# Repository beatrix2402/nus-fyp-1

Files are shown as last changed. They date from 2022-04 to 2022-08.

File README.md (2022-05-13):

# A low-cost device to detect angle closure glaucoma
This repository was created as part of my final year project at the National University of Singapore under the Department of Biomedical Engineering.

In this project, the development of a device using low-cost materials was explored to facilitate the [Standard Flashlight Test (SFT)](https://www.ncbi.nlm.nih.gov/pmc/articles/PMC5130941/), a simple test done that checks for primary angle closure glaucoma (PACG) in patients. This device was created with the intention of independent use by users regardless of technological skills as majority of the target audience are elderly.

## About the Project
A lightweight 3D-printed device (`CAD_files`) was built to solve the problem of infrequent testing for angle closure, which often lead to the unsuspected development of the disease and irreversible blindness. The device runs a Python code on a Raspberry Pi Zero (`startup_code_fyp.py`) to capture images of a patient’s eye with a camera and a light source. Thereafter, a deep learning algorithm built with PyTorch (`segmentation_code.ipynb`) segments the iris and determines the grading of primary angle closure suspect. The result is displayed to the patient through the device.

## About the Repository
In this repository, you will find the device code (`startup_code_fyp.py`), segmentation code (`segmentation_code`) and the CAD files used to print the device (`CAD_files`). Both are written in Python.

**The data for the segmentation code is not provided.** Please request it if necessary from marisa.lim@u.nus.edu.

## Segmentation Code
In the `segmentation_code` folder, you will find the models and Python notebook used. The `.html` and `.pdf` versions of the Python notebook are also included.

The necessary outputs are kept within for a better understanding of the notebook.

## Start-up Code
This Python code is run on a Raspberry Pi Zero in the device to automate the Standard Flashlight Test. The Raspberry Pi GPIO library was used.

## CAD Files
There are three components to the 3D-printed device: box top, box bottom, and LED holder. These are found in the `CAD_files` folder, which contains both the `.stl` and original SolidWorks files. An assembly file is also included within to visualise the three components together, with an additional eye cup to simulate the silicon eye cup that is attached later on.

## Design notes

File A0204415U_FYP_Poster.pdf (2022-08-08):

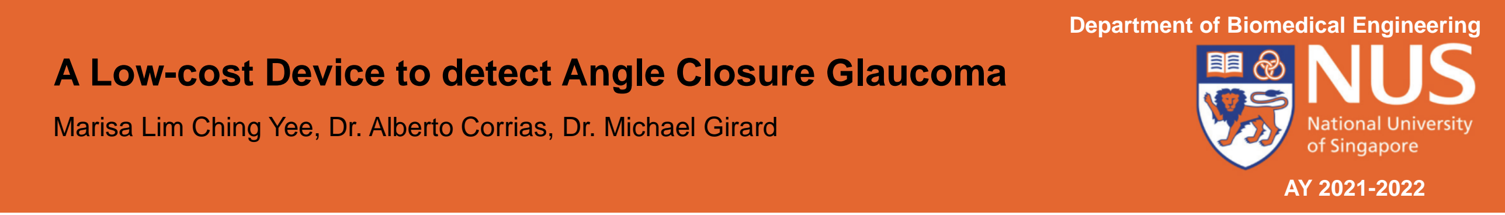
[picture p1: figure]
Department of Biomedical Engineering

## A Low-cost Device to detect Angle Closure Glaucoma

### Marisa Lim Ching Yee, Dr. Alberto Corrias, Dr. Michael Girard

- A device using low-cost materials was developed to automate the Standard Flashlight Test (SFT).
- PACG is a potentially preventable type of glaucoma if detected early enough with frequent screening. However, current screening techniques require professional supervision under a clinical setting [1].
- The SFT provides a cheap and convenient solution to accurately to identify risks of PACG in patients [3].
- By simply analysing the shadow cast over the iris by a beam of parallel light, the depth of the anterior chamber can be inferred, indicating if there is risk of PACG [Fig. 1, 4].

### Introduction

### Hardware Methodology

To automate the SFT process, these key items were used:
- A lightweight Raspberry Pi Zero microprocessor.
- Monocular-design casing 3D-printed with polylactic acid (PLA). Users simply rotate device to test each eye [Fig. 2].
- Tactile and audio prompts are given to the user during the SFT process when their vision is restricted.
- A silicon eyecup for users to position the tested eye.

Fig 2.
Components in
3D-printed PLA
casing.

### Software Methodology

Fig 3.
Categorisation
of grades of
PACG risk.

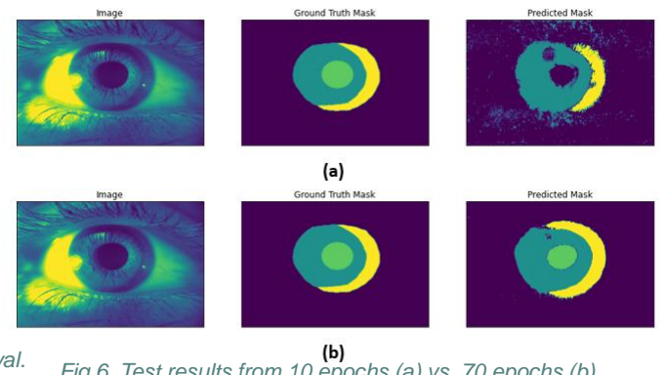
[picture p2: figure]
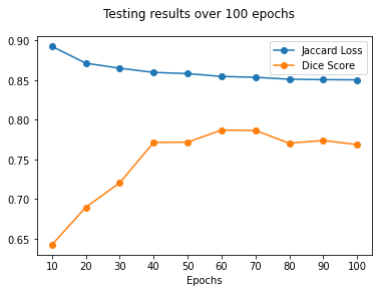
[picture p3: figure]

- While the segmentation of out-of-sample Grade 3 images was not as clean as those for Grade 1, the segments were still accurately identified [Fig. 7].
- A shadow-to-iris ratio was calculated by taking the area of the shadow (yellow) against that of the whole iris (teal, green and yellow). The larger the shadow area, the higher the ratio, thus indicating a higher risk of PACG (i.e., Grade 1).
Average ratio for Grade 1 = 0.2 Average ratio for Grade 3 = 0.199
- The minute difference can be attributed to the much smaller dataset for Grade 1, making the ratio unrepresentative of all Grade 1 eyes.
- Device was operated by the user with the help of an assistant of any skill level to guide their eyes [Fig. 4].
- Resulting images were of sufficient clarity, even capturing crypts with high definition, and the shadow cast on the iris by the light source can be clearly seen.

### Results and Discussion

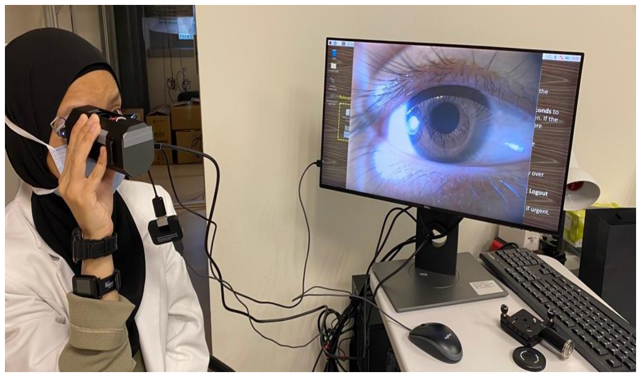
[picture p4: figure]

Fig 4. Example of resulting image (left) from the SFT process (right).

Fig 5. Testing results at each 10-epoch interval. Fig 6. Test results from 10 epochs (a) vs. 70 epochs (b).

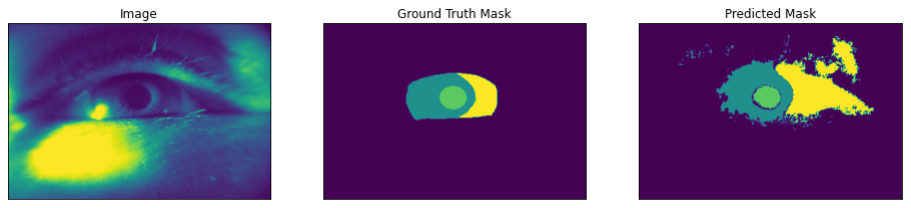
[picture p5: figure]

Fig 7. Test results on out-of-sample data from 70 training epochs.

[1] Sharma et al., 2008 – Diagnostic tools for glaucoma detection and management
[2] Shikino et. al, 2016 – Oblique flashlight test: Lighting up acute angle-closure Glaucoma
[3] Nongpiur et al., 2010 – Novel association of smaller anterior chamber width with angle closure in Singaporeans
[4] Sidhartha et al., 2014 – Relationship between iris surface features and angle width in Asian eyes

### References

- The device was successfully used without professional supervision to capture high quality images of the iris for Grade 1 and 3 users.
- The segmentation model was successfully trained to perform segmentation and obtain a ratio for multiclass classification into respective risk grades.
- Further training with other grades will allow development of a robust classification algorithm. Other factors indicating PACG risk such as crypt presence and eye colour can also be considered [4].
- Integration of the model onto the Raspberry Pi Zero via ONNX is recommended.

### Conclusion

A PyTorch deep learning algorithm was developed to identify 3 grades of PACG risk (Grades 1, 2, 3) [Fig. 3]. This stage focused on iris segmentation.

- 58 Grade 3 and 4 Grade 1 eyes.
- Segments: iris, shadow, pupil, others.
- All images were captured on device.
Building the Dataset | Model Training and Testing
| Training ▪ 100 epochs in total; data pulled, and best model saved every 10 epochs. Testing ▪ Each model was tested on Grade 3 testing set and out-of-sample Grade 1

testing set 4 (out-of-sample test)

41 (train) | 17 (test)

Fig. 1. Schematic of SFT.

- Optimal number of training epochs: 70 epochs [Fig. 5, 6].

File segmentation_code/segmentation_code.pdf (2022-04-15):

# Data Folder

The dataset is made up of images from three grades of PACS, in decreasing order of risk of PACG:

Grade 1 (G1) - high risk
Grade 2 (G2)
Grade 3 (G3) - low risk

Dataset is organised as such:

FOLDER NAME: "Data"

G3
images_original
images
labels
G2
(same as G1)
G1
(same as G1)

images_original contains the original RGB images obtained from the Raspberry Pi. images contains the pre-processed images into grayscale which will be used for the training and testing of the model. labels contains the segmentation PNG files from AVIZO.

# Data pre-processing

All images must first be converted from RGB to grayscale. These images will be stored in the "images" folder in each grade folder.

(1944, 2592, 3)
<matplotlib.image.AxesImage at 0x20dc1121940>

(1944, 2592, 3)
<matplotlib.image.AxesImage at 0x20dc1189430>

# Load data

Allocate pre-processed images from "images" and target from "labels" into train and test set.

In this code, the model is only trained on G3 images. G1 images are used as out-of-sample test data.

Number of Grade 3 images: 58 Total number of images: 58

Number of Training images: 41 Number of Testing images: 17

## Visualize function

Takes in images as arrays and prints them using Matplotlib.

## Dataloader

Writing helper class for data extraction, tranformation and preprocessing https://pytorch.org/docs/stable/data

Done!

## Augmentations

Data augmentation is a powerful technique to increase the amount of your data and prevent model overfitting. If you not familiar with such trick read some of these articles:

The Effectiveness of Data Augmentation in Image Classification using Deep Learning (http://cs231n.stanford.edu/reports/2017/pdfs/300.pdf)
Data Augmentation | How to use Deep Learning when you have Limited Data (https://medium.com/nanonets/how-to-use-deep-learning-when-you-have-limited-data-part-2-data-augmentation-c26971dc8ced)
Data Augmentation Experimentation (https://towardsdatascience.com/data-augmentation-experimentation-3e274504f04b)

Since our dataset is very small we will apply a large number of different augmentations:

horizontal flip
affine transforms
perspective transforms
brightness/contrast/colors manipulations image bluring and sharpening gaussian noise
random crops

All this transforms can be easily applied with Albumentations (https://github.com/albu/albumentations/) - fast augmentation library. For detailed explanation of image transformations you can look at kaggle salt segmentation exmaple (https://github.com/albu/albumentations/blob/master/notebooks/example_kaggle_salt.ipynb) provided by Albumentations (https://github.com/albu/albumentations/) authors.

Size of augmented dataset: 41

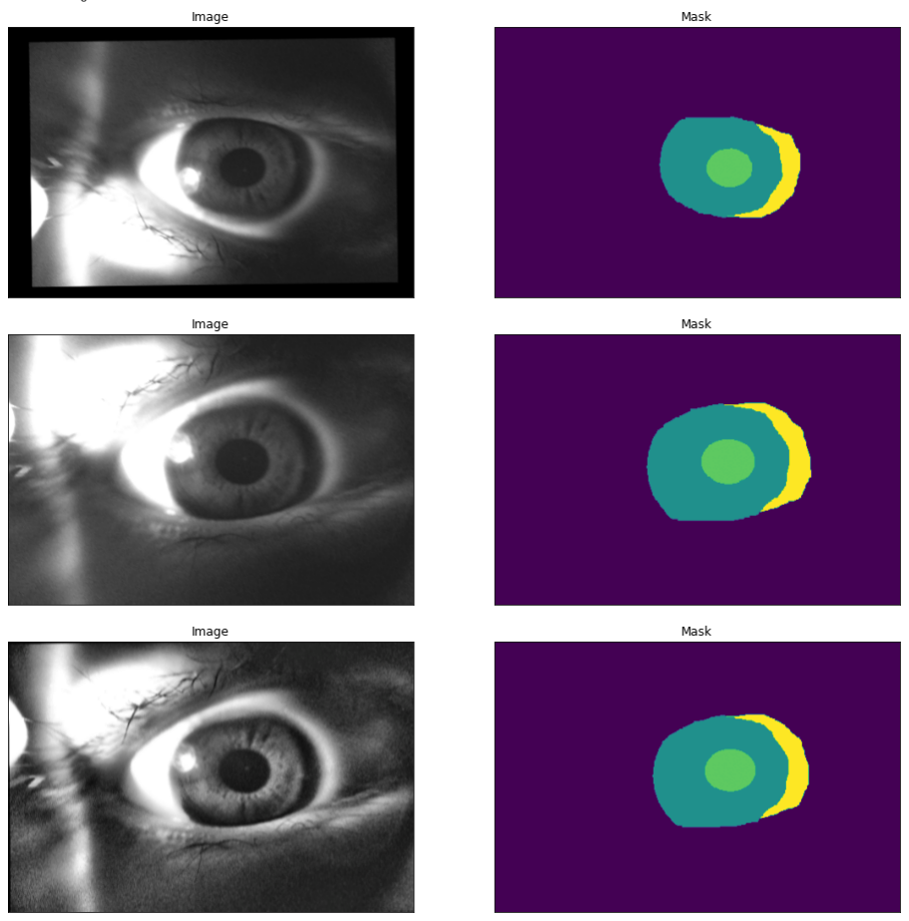
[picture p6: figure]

# Create model and train

Epoch: 0
train: 100%|█████████████████████████████████████| 6/6 [01:08<00:00, 11.44s/it, jaccard_loss - 0.8559, fscore - 0.7569] Model saved!

Epoch: 1
train: 100%|█████████████████████████████████████| 6/6 [01:00<00:00, 10.07s/it, jaccard_loss - 0.8608, fscore - 0.7371] Decrease decoder learning rate to 1e-5!

Epoch: 2
train: 100%|█████████████████████████████████████| 6/6 [00:57<00:00, 9.59s/it, jaccard_loss - 0.8667, fscore - 0.7235]

Epoch: 3
train: 100%|█████████████████████████████████████| 6/6 [00:57<00:00, 9.51s/it, jaccard_loss - 0.8582, fscore - 0.7497]

Epoch: 4
train: 100%|███████████████████████████████████████| 6/6 [00:57<00:00, 9.54s/it, jaccard_loss - 0.8567, fscore - 0.75]

Epoch: 5
train: 100%|█████████████████████████████████████| 6/6 [00:57<00:00, 9.61s/it, jaccard_loss - 0.8566, fscore - 0.7576] Model saved!

Epoch: 6
train: 100%|█████████████████████████████████████| 6/6 [00:59<00:00, 9.87s/it, jaccard_loss - 0.8617, fscore - 0.7335]

Epoch: 7
train: 100%|███████████████████████████████████████| 6/6 [00:57<00:00, 9.59s/it, jaccard_loss - 0.85, fscore - 0.7545]

Epoch: 8
train: 100%|███████████████████████████████████████| 6/6 [00:56<00:00, 9.50s/it, jaccard_loss - 0.859, fscore - 0.743]

Epoch: 9
train: 100%|█████████████████████████████████████| 6/6 [00:57<00:00, 9.55s/it, jaccard_loss - 0.8602, fscore - 0.7318]

# Test best saved model on G3 test data

Model is tested on the pre-allocated test data (G3). The model used below is extracted after 70 training epochs, which is the optimal training duration (see last section: Results and Plotting).

valid: 100%|███████████████████████████████████| 17/17 [00:11<00:00, 1.47it/s, jaccard_loss - 0.8536, fscore - 0.7866]

# Visualize testing predictions

All testing predictions will be saved into a folder called "results".

# Finding colour ratio

This will give some insight into the ratio of the shadow to iris.

RGB values:

White: (255, 255, 255)
Dark purple (background colour): (68, 1, 84) Teal (iris): (32, 144, 140)
Yellow (shadow): (253, 231, 36)
Green (pupil): (94, 201, 97)
Black: (13, 0, 17)

*Numbers with very similar values can be counted towards the colour category

FOR IMAGE: ./Data/G3/results/TRAINING7_0.png | Ratio: 0.1478351319724353
FOR IMAGE: ./Data/G3/results/TRAINING7_1.png | Ratio: 0.1515783618411904
FOR IMAGE: ./Data/G3/results/TRAINING7_2.png | Ratio: 0.22361336076697458
FOR IMAGE: ./Data/G3/results/TRAINING7_3.png | Ratio: 0.22768361581920904
FOR IMAGE: ./Data/G3/results/TRAINING7_4.png | Ratio: 0.1980398100434475
FOR IMAGE: ./Data/G3/results/TRAINING7_5.png | Ratio: 0.1462166364343094
FOR IMAGE: ./Data/G3/results/TRAINING7_6.png | Ratio: 0.24132389349780653
FOR IMAGE: ./Data/G3/results/TRAINING7_7.png | Ratio: 0.18103517026876145
FOR IMAGE: ./Data/G3/results/TRAINING7_8.png | Ratio: 0.239057524941626
FOR IMAGE: ./Data/G3/results/TRAINING7_9.png | Ratio: 0.21289220107276782
FOR IMAGE: ./Data/G3/results/TRAINING7_10.png | Ratio: 0.24365106479899784
FOR IMAGE: ./Data/G3/results/TRAINING7_11.png | Ratio: 0.1893248879962923
FOR IMAGE: ./Data/G3/results/TRAINING7_12.png | Ratio: 0.18408450073848634
FOR IMAGE: ./Data/G3/results/TRAINING7_13.png | Ratio: 0.15226569096538137
FOR IMAGE: ./Data/G3/results/TRAINING7_14.png | Ratio: 0.17349596319124924
FOR IMAGE: ./Data/G3/results/TRAINING7_15.png | Ratio: 0.24597881522165554
FOR IMAGE: ./Data/G3/results/TRAINING7_16.png | Ratio: 0.21564569536423842

# Out-of-sample G1 test data

There are currently 4 G1 images, which will be used as out-of-sample test data to evaluate the ability of the model to run on different grades.

valid: 100%|█████████████████████████████████████| 4/4 [00:02<00:00, 1.63it/s, jaccard_loss - 0.9448, fscore - 0.5109]

FOR IMAGE: ./Data/G3/results/OOS_TRAINING7_0.png | Ratio: 0.15514764565043895
FOR IMAGE: ./Data/G3/results/OOS_TRAINING7_1.png | Ratio: 0.18888546798029557
FOR IMAGE: ./Data/G3/results/OOS_TRAINING7_2.png | Ratio: 0.16101873289833718
FOR IMAGE: ./Data/G3/results/OOS_TRAINING7_3.png | Ratio: 0.2977827673309009

# Results and Plotting

The following results were collected after training and testing of the model over 100 epochs, and data was collected every 10 epochs to find the optimal training epoch number.

In [ ]:
import os, glob, shutil
os.environ['CUDA_VISIBLE_DEVICES'] = ''

import numpy as np
import cv2
import matplotlib
import matplotlib.pyplot as plt import matplotlib._png as png import torch
from PIL import Image
#from time import process_time

#torch.cuda.empty_cache()

print("Import done")

In [22]:
DATA_DIR = './Data/' # change as per the name of the data folder

In [23]:
# CONVERT IMAGES TO GRAYSCALE

def processSkinImage(filePath):
# step 1

# read the image

original = cv2.imread(filename=filePath)

# step 2

# convert the image from rgb to grayscale

image_gray = cv2.cvtColor(original, cv2.COLOR_BGR2GRAY)

return image_gray

In [ ]:
# Process G3 images

path = './Data/G3/images_original' path_processed = './Data/G3/images'
for mainDir, subDir, fileList in os.walk(path): for file in fileList:
currentPath = os.path.join(mainDir, file) processedImage = processSkinImage(currentPath)

new_mainDir = path_processed + mainDir.split(path)[-1]
if not os.path.exists(new_mainDir): os.makedirs(new_mainDir)
cv2.imwrite(os.path.join(new_mainDir, file), processedImage)

print("G3 images processed")

# Process G1 images

path = './Data/G1/images_original' path_processed = './Data/G1/images'
for mainDir, subDir, fileList in os.walk(path): for file in fileList:
currentPath = os.path.join(mainDir, file) processedImage = processSkinImage(currentPath)

new_mainDir = path_processed + mainDir.split(path)[-1]
if not os.path.exists(new_mainDir): os.makedirs(new_mainDir)
cv2.imwrite(os.path.join(new_mainDir, file), processedImage)

print("G1 images processed")

In [25]:
# SHOW SAMPLE OF ORIGINAL IMAGE

filePath = "./Data/G3/images_original/G3_L1.png" original = cv2.imread(filename=filePath)
original = cv2.cvtColor(original, cv2.COLOR_BGR2RGB) print(original.shape)
plt.imshow(original)

# Out[25]: In [26]:

# SHOW SAMPLE OF GRAYSCALED IMAGE

filePath = "./Data/G3/images/G3_L1.png" gray = cv2.imread(filename=filePath) print(gray.shape)
plt.imshow(gray, cmap='gray')

# Out[26]: In [27]:

import fnmatch

num_G3_total = len(fnmatch.filter(os.listdir('./Data/G3/images/'),'*.png')) # Grade 3 - Healthy eyes #num_G2_total = len(fnmatch.filter(os.listdir('./Data/G2/images/'),'*.png')) # Grade 2 num_G1_total = len(fnmatch.filter(os.listdir('./Data/G1/images/'),'*.png')) # Grade 1
print( 'Number of Grade 3 images:', num_G3_total) #58

print( 'Total number of images:', num_G3_total) # + num_G2_total+ num_G1_total

In [28]:
# ALLOCATE TRAIN AND TEST

# percentage used for testing - can be changed percentage_testing = 0.3

num_G3_testing = int(num_G3_total * percentage_testing) num_G3_training = num_G3_total - num_G3_testing

num_training = num_G3_training #+ num_G2_training + num_G1_training num_testing = num_G3_testing #+ num_G2_testing + num_G1_testing print( 'Number of Training images:', num_training)
print( 'Number of Testing images:', num_testing)

files_G3_images = sorted(os.listdir(os.path.join('./Data/G3/images/'))) files_G3_labels = sorted(os.listdir(os.path.join('./Data/G3/labels/')))

In [29]:
k = 0
row = 256
col = 256
num_classes = 5 # CHANGE ACCORDING TO HOW MANY MATERIALS used in segmentation

# Define some arrays --- This is for Keras

X_train | = np.ndarray(shape=(num_training, row, col, | 1), dtype='d')
Y_train | = np.ndarray(shape=(num_training, row, col, num_classes), dtype='d')
X_test | = np.ndarray(shape=(num_testing , row, col, | 1), dtype='d')
Y_test | = np.ndarray(shape=(num_testing , row, col, num_classes), dtype='d')

In [ ]:
# Training Set--------------------------------------------------------------------------------print("TRAINING SET:")

for i in range(num_G3_training):

# add image

im = plt.imread(os.path.join('./Data/G3/images/',files_G3_images[i+1])) X_train[k,:,:,0] = cv2.resize(im, dsize=(col, row), interpolation=cv2.INTER_LINEAR)

la = plt.imread(os.path.join('./Data/G3/labels/',files_G3_labels[i+1]))

# add label

rla = cv2.resize(la[:,:], dsize=(col, row), interpolation=cv2.INTER_NEAREST) for j in range(num_classes):
| temp = np.copy(rla)+1 temp[temp!=j+1] = 0 Y_train[k,:,:,j] = temp/(j+1)

k = k+1
print(files_G3_images[i+1]+', '+files_G3_labels[i+1]+' added')

print("Done!")

In [ ]:
# Testing Set--------------------------------------------------------------------------------print("TESTING SET:")

k=0
for i in range(num_G3_testing):

# add image

im = plt.imread(os.path.join('./Data/G3/images/',files_G3_images[num_G3_training+1+i])) X_test[k,:,:,0] = cv2.resize(im, dsize=(col, row), interpolation=cv2.INTER_LINEAR)

# add label

la = plt.imread(os.path.join('./Data/G3/labels/',files_G3_labels[num_G3_training+i])) rla = cv2.resize(la[:,:], dsize=(col, row), interpolation=cv2.INTER_NEAREST)

for j in range(num_classes):
| temp = np.copy(rla)+1 temp[temp!=j+1] = 0 Y_test[k,:,:,j] = temp/(j+1)

k = k+1

print(files_G3_images[num_G3_training+1+i]+', '+files_G3_labels[num_G3_training+i]+' added')
#if "list index out of range" just add +1 or remove +1. This is due to the .ipynb_checkpoints folder

print("Done!")

In [ ]:
# Direct into Train, Validation, and Test Folders x_train_dir = os.path.join(DATA_DIR, 'train') y_train_dir = os.path.join(DATA_DIR, 'trainannot') #x_valid_dir = os.path.join(DATA_DIR, 'val') #y_valid_dir = os.path.join(DATA_DIR, 'valannot')

x_test_dir = os.path.join(DATA_DIR, 'test')
y_test_dir = os.path.join(DATA_DIR, 'testannot')

# We delete all the files in them in case we want to change the proportions for f in glob.glob(os.path.join(x_train_dir,'*')): os.remove(f)

for f in glob.glob(os.path.join(y_train_dir,'*')): os.remove(f)
for f in glob.glob(os.path.join(x_test_dir,'*')): os.remove(f)
for f in glob.glob(os.path.join(y_test_dir,'*')): os.remove(f)

# Training Set--------------------------------------------------------------------------------print("TRAIN FOLDERS:")

for i in range(num_G3_training): shutil.copy(os.path.join('./Data/G3/images/',files_G3_images[i+1]), x_train_dir) shutil.copy(os.path.join('./Data/G3/labels/',files_G3_labels[i+1]), y_train_dir) print(files_G3_images[i+1]+', '+files_G3_labels[i+1]+' copied!')

# Testing Set--------------------------------------------------------------------------------print("TEST FOLDERS:")

for i in range(num_G3_testing): shutil.copy(os.path.join('./Data/G3/images/',files_G3_images[num_G3_training+1+i]), x_test_dir) shutil.copy(os.path.join('./Data/G3/labels/',files_G3_labels[num_G3_training+i]), y_test_dir) print(files_G3_images[num_G3_training+1+i]+', '+files_G3_labels[num_G3_training+i]+' copied!')

In [33]:
# helper function for data visualization def visualize(**images):

"""Plot images in one row."""
n = len(images)
plt.figure(figsize=(16, 5))
for i, (name, image) in enumerate(images.items()): plt.subplot(1, n, i + 1)
plt.xticks([])
plt.yticks([])
plt.title(' '.join(name.split('_')).title()) plt.imshow(image)
plt.show()

In [34]:
from torch.utils.data import DataLoader
from torch.utils.data import Dataset as BaseDataset

In [35]:
class Dataset(BaseDataset):
"""CamVid Dataset. Read images, apply augmentation and preprocessing transformations.

Args:
images_dir (str): path to images folder
masks_dir (str): path to segmentation masks folder
class_values (list): values of classes to extract from segmentation mask augmentation (albumentations.Compose): data transfromation pipeline (e.g. flip, scale, etc.)
preprocessing (albumentations.Compose): data preprocessing
(e.g. noralization, shape manipulation, etc.)

"""

CLASSES = ['0','1', '2', '3','4'] # 4 materials used in segmentation

def __init__(
self,
images_dir,
masks_dir,
classes=None,
augmentation=None,
preprocessing=None,
):
self.ids = sorted(os.listdir(images_dir))
self.images_fps = [os.path.join(images_dir, image_id) for image_id in self.ids]
#self.masks_fps = [os.path.join(masks_dir, image_id) for image_id in self.ids]

self.masks_fps = [os.path.join(masks_dir, image_id) for image_id in sorted(os.listdir(masks_dir))]

# convert str names to class values on masks

self.class_values = [self.CLASSES.index(cls.lower()) for cls in classes]

self.augmentation = augmentation
self.preprocessing = preprocessing

def __getitem__(self, i):

# read data

image = cv2.imread(self.images_fps[i])
image = cv2.resize(image, dsize=(480, 320), interpolation=cv2.INTER_NEAREST)

mask = cv2.imread(self.masks_fps[i], 0)
mask = cv2.resize(mask, dsize=(480, 320), interpolation=cv2.INTER_NEAREST)

# extract certain classes from mask (e.g. cars)

masks = [(mask == v) for v in self.class_values]
mask = np.stack(masks, axis=-1).astype('float')

# apply augmentations

if self.augmentation:
sample = self.augmentation(image=image, mask=mask) image, mask = sample['image'], sample['mask']

# apply preprocessing

if self.preprocessing:
sample = self.preprocessing(image=image, mask=mask) image, mask = sample['image'], sample['mask']

return image, mask

def __len__(self):
return len(self.ids)

In [36]:
# Lets look at data we have

dataset = Dataset(x_train_dir, y_train_dir, classes=['0','1','2','3','4']) # Somehow need one more class than required to work print("Done!")

In [37]:
# print sample 0

i = 0
image, mask = dataset[i] # get some sample

mask2 = np.zeros((mask.shape[0], mask.shape[1])) for i in range(num_classes):
mask2 += mask[:,:,i]*i

visualize(
image=image,
seg_mask=mask2.squeeze(),
)

In [ ]:
# print everything

for i in range(num_training):
image, mask = dataset[i] # get some sample

mask2 = np.zeros((mask.shape[0], mask.shape[1])) for i in range(num_classes):
mask2 += mask[:,:,i]*i

visualize(
image=image,
seg_mask=mask2.squeeze(),
)

In [38]:
import albumentations as albu

In [39]:
# ORIGINAL AUGMENTATIONS

def get_training_augmentation():

train_transform = [

albu.VerticalFlip(p=0.5), # Vertical flip to simulate difference between left and right eye.

albu.ShiftScaleRotate(scale_limit=0.1, rotate_limit=1, shift_limit=0.01, p=1, border_mode=0),

#albu.RandomBrightness(limit=0.1, p=0.8),

#albu.RandomContrast(limit=0.1, p=0.8),

#albu.Blur(blur_limit=3, p=0.8),

#albu.MotionBlur(blur_limit=3, p=0.8),

albu.OneOf(
[
albu.CLAHE(p=1),
albu.RandomBrightness(limit=0.1, p=1), albu.RandomGamma(p=1),
],
p=0.8,
),

albu.OneOf(
[
# | albu.IAASharpen(p=1),

| albu.Blur(blur_limit=3, p=1),
| albu.MotionBlur(blur_limit=3, p=1),
],
p=0.8,
),

albu.OneOf(
[
| albu.RandomContrast(p=1),
],
p=0.5,
),
]
return albu.Compose(train_transform)

def get_validation_augmentation():
"""Add paddings to make image shape divisible by 32""" test_transform = [
albu.PadIfNeeded(384, 480)
]
return albu.Compose(test_transform)

def to_tensor(x, **kwargs):
return x.transpose(2, 0, 1).astype('float32')

def get_preprocessing(preprocessing_fn): """Construct preprocessing transform

Args:
preprocessing_fn (callbale): data normalization function (can be specific for each pretrained neural network) Return:
transform: albumentations.Compose

"""

_transform = [
albu.Lambda(image=preprocessing_fn), albu.Lambda(image=to_tensor, mask=to_tensor), ]
return albu.Compose(_transform)

In [42]:
#### Visualize resulted augmented images and masks

augmented_dataset = Dataset(
x_train_dir,
y_train_dir,
augmentation=get_training_augmentation(), classes=['0','1','2','3','4'],
)

print("Size of augmented dataset: ", len(augmented_dataset))

# same image with different random transforms

for i in range(3):
image, mask = augmented_dataset[0]
mask2 = np.zeros((mask.shape[0], mask.shape[1])) for j in range(num_classes): mask2 += mask[:,:,j]*j visualize(image=image, mask=mask2.squeeze())

In [50]:
import torch
import numpy as np
import segmentation_models_pytorch as smp

In [ ]:
ENCODER = 'resnet34'
ENCODER_WEIGHTS = 'imagenet'
CLASSES = ['0','1','2','3','4']
ACTIVATION = 'softmax2d' # could be None for logits or 'softmax2d' for multicalss segmentation DEVICE = 'cpu' #cuda

# create segmentation model with pretrained encoder

model = smp.UnetPlusPlus(
encoder_name=ENCODER,
encoder_weights=ENCODER_WEIGHTS, #in_channels=1,
classes=len(CLASSES),
activation=ACTIVATION,
)

preprocessing_fn = smp.encoders.get_preprocessing_fn(ENCODER, ENCODER_WEIGHTS) print("Model created!")

In [ ]:
train_dataset = Dataset(
x_train_dir,
y_train_dir,
augmentation=get_training_augmentation(), preprocessing=get_preprocessing(preprocessing_fn), classes=CLASSES,
)

print("Data loaded!")

train_loader = DataLoader(train_dataset, batch_size=8, shuffle=True, num_workers=0)
# issue resolved (num_workers): https://github.com/pytorch/pytorch/issues/5301

In [53]:
# Dice/F1 score - https://en.wikipedia.org/wiki/S%C3%B8rensen%E2%80%93Dice_coefficient # IoU/Jaccard score - https://en.wikipedia.org/wiki/Jaccard_index

loss = smp.utils.losses.JaccardLoss()
metrics = [
#smp.utils.metrics.IoU(threshold=0.5), smp.utils.metrics.Fscore(threshold=0.5),

]

optimizer = torch.optim.Adam([ dict(params=model.parameters(), lr=0.0001), ])

In [ ]:
# create epoch runners

# it is a simple loop of iterating over dataloader`s samples train_epoch = smp.utils.train.TrainEpoch(

model,
loss=loss,
metrics=metrics,
optimizer=optimizer,
device=DEVICE,
verbose=True,
)

print("Done!")

In [324…
# train model for specific number of epochs

max_score = 0

for i in range(0, 10): # CHANGE THE NUMBER OF EPOCHS

print('\nEpoch: {}'.format(i))
train_logs = train_epoch.run(train_loader)

torch.save(model.state_dict(),'./essai.pth')

# do something (save model, change lr, etc.) if max_score < train_logs['fscore']:

max_score = train_logs['fscore']

# ALWAYS CHANGE THE NAME OF THE SAVED MODEL

torch.save(model, './Models/best_model_training_epoch_100.pth') print('Model saved!')

if i == 1:
optimizer.param_groups[0]['lr'] = 1e-5
print('Decrease decoder learning rate to 1e-5!')

In [55]:
# load best saved checkpoint

best_model = torch.load('./Models/best_model_training_epoch_70.pth') # MUST CHANGE THE NAME AS WELL

In [56]:
# create test dataset with G3 data

test_dataset = Dataset(
x_test_dir,
y_test_dir,
preprocessing=get_preprocessing(preprocessing_fn), classes=CLASSES,
)

test_dataloader = DataLoader(test_dataset)

In [57]:
# evaluate model on test set

test_epoch = smp.utils.train.ValidEpoch( model=best_model,
loss=loss,
metrics=metrics,
device=DEVICE,
)

logs = test_epoch.run(test_dataloader) # COPY THE LOGS AND STORE IT SOMEWHERE

In [59]:
# test dataset without transformations for image visualization test_dataset_vis = Dataset(

x_test_dir, y_test_dir,
classes=CLASSES,
)

In [61]:
# Show samples

for n in range(1):

image_vis = test_dataset_vis[n][0].astype('uint8') image, gt_mask = test_dataset[n]

gt_mask = gt_mask.squeeze()

x_tensor = torch.from_numpy(image).to(DEVICE).unsqueeze(0) pr_mask = best_model.predict(x_tensor)
pr_mask = (pr_mask.squeeze().cpu().numpy().round())

#reshape gt and pr masks

gt_mask2 = np.zeros((gt_mask.shape[1], gt_mask.shape[2])) pr_mask2 = np.zeros((pr_mask.shape[1], pr_mask.shape[2])) for i in range(num_classes): gt_mask2 += gt_mask[i,:,:]*i for i in range(num_classes): pr_mask2 += pr_mask[i,:,:]*i

visualize(
image=image[0,:,:],
ground_truth_mask=gt_mask2,
predicted_mask=pr_mask2
)

In [ ]:
# Visualise everything

for n in range(len(test_dataset)):

image_vis = test_dataset_vis[n][0].astype('uint8') image, gt_mask = test_dataset[n]

gt_mask = gt_mask.squeeze()

x_tensor = torch.from_numpy(image).to(DEVICE).unsqueeze(0) pr_mask = best_model.predict(x_tensor)
pr_mask = (pr_mask.squeeze().cpu().numpy().round())

#reshape gt and pr masks

gt_mask2 = np.zeros((gt_mask.shape[1], gt_mask.shape[2])) pr_mask2 = np.zeros((pr_mask.shape[1], pr_mask.shape[2])) for i in range(num_classes): gt_mask2 += gt_mask[i,:,:]*i for i in range(num_classes): pr_mask2 += pr_mask[i,:,:]*i

visualize(
image=image[0,:,:],
ground_truth_mask=gt_mask2,
predicted_mask=pr_mask2
)

In [235…
# custom function to save figures

def saveVisualized(**images): """Plot images in one row."""
n = len(images)
plt.figure(figsize=(16, 5))
for i, (name, image) in enumerate(images.items()): plt.subplot(1, n, i + 1)
plt.xticks([])
plt.yticks([])
plt.title(' '.join(name.split('_')).title()) plt.imshow(image)
#plt.show()

In [ ]:
filedir = os.path.join('./Data/G3/results/')

for n in range(len(test_dataset)):
#n = np.random.choice(len(test_dataset))

image, gt_mask = test_dataset[n]

gt_mask = gt_mask.squeeze()

x_tensor = torch.from_numpy(image).to(DEVICE).unsqueeze(0) pr_mask = best_model.predict(x_tensor)
pr_mask = (pr_mask.squeeze().cpu().numpy().round())

#reshape gt and pr masks

gt_mask2 = np.zeros((gt_mask.shape[1], gt_mask.shape[2])) pr_mask2 = np.zeros((pr_mask.shape[1], pr_mask.shape[2])) for i in range(num_classes): gt_mask2 += gt_mask[i,:,:]*i for i in range(num_classes): pr_mask2 += pr_mask[i,:,:]*i

saveVisualized(
Predicted_Mask=pr_mask2
)

print('Saving TRAINING7_'+str(n)+'.png ...')
plt.savefig(filedir + 'TRAINING7_'+str(n)+'.png') #change number accordingly

print("All test results have been saved!")

In [209…
def getShadowRatio(filePath):

# STEP 1: get array of all the pixels and colours in the image file

img = Image.open(os.path.join(filePath))
colours = img.convert('RGB').getcolors(img.size[0]*img.size[1]) #uses RGB format colours.sort()
colours.reverse()
main_colours = colours[:5] # get only the top 5 colours used
#print("Top five colours: ", main_colours)

# STEP 2: count shadow and iris pixels according to colours

# assume that colours are standardised (can check by printing top 5 colours of all images) shadow, iris = 0, 0

for n in range(len(main_colours)):

pixels = main_colours[n][0]
rgbval = main_colours[n][1]

if rgbval == (253, 231, 36): #yellow - shadow shadow = pixels
iris += pixels
elif rgbval == (32, 144, 140): #teal - iris iris += pixels
elif rgbval == (94, 201, 97): #green - pupil
iris += pixels

#print("FOR IMAGE ", filePath)

#print("Shadow pixels: ", shadow, " | Iris pixels: ", iris)

shadow_ratio = shadow/iris
return shadow_ratio

In [219…
for i in range(len(test_dataset)):
filePath = './Data/G3/results/TRAINING7_'+str(i)+'.png' ratio = getShadowRatio(filePath)
print("FOR IMAGE: ", filePath, " | Ratio: ", ratio)

In [62]:
best_model = torch.load('./Models/best_model_training_epoch_70.pth') # MUST CHANGE THE NAME AS WELL

In [63]:
x_oostest_dir = os.path.join('./Data/G1/images')
y_oostest_dir = os.path.join('./Data/G1/labels')

In [64]:
# create OOS test dataset with G1 data oostest_dataset = Dataset(

x_oostest_dir,
y_oostest_dir,
#augmentation=get_validation_augmentation(), preprocessing=get_preprocessing(preprocessing_fn), classes=CLASSES,

)

oostest_dataloader = DataLoader(oostest_dataset)

In [65]:
# evaluate model on test set

test_epoch = smp.utils.train.ValidEpoch( model=best_model,
loss=loss,
metrics=metrics,
device=DEVICE,
)

logs = test_epoch.run(oostest_dataloader) # COPY THE LOGS AND STORE IT SOMEWHERE

In [67]:
# test dataset without transformations for image visualization oostest_dataset_vis = Dataset(

x_oostest_dir, y_oostest_dir,
classes=CLASSES,
)

In [72]:
# Show sample

n = 2

image_vis = oostest_dataset_vis[n][0].astype('uint8') image, gt_mask = oostest_dataset[n]

gt_mask = gt_mask.squeeze()

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

#reshape gt and pr masks

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

visualize(
image=image[0,:,:],
ground_truth_mask=gt_mask2,
predicted_mask=pr_mask2
)

In [ ]:
# Show everything

for n in range(len(test_dataset)):

image_vis = oostest_dataset_vis[n][0].astype('uint8') image, gt_mask = oostest_dataset[n]

gt_mask = gt_mask.squeeze()

# To find out: why is image not between 0 and 1? #print(image.shape)

#print(image.dtype)

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

#reshape gt and pr masks

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

visualize(
image=image[0,:,:],
ground_truth_mask=gt_mask2,
predicted_mask=pr_mask2
)

In [ ]:
filedir = os.path.join('./Data/G3/results/')

for n in range(len(oostest_dataset)):
#n = np.random.choice(len(test_dataset))

image, gt_mask = oostest_dataset[n]

gt_mask = gt_mask.squeeze()

# To find out: why is image not between 0 and 1? #print(image.shape)

#print(image.dtype)

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

#reshape gt and pr masks

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

saveVisualized(
Predicted_Mask=pr_mask2
)

print('Saving OOS_TRAINING7_'+str(n)+'.png ...')
plt.savefig(filedir + 'OOS_TRAINING7_'+str(n)+'.png') #change number accordingly

print("All test results have been saved!")

In [270…
for i in range(len(oostest_dataset)):
filePath = './Data/G3/results/OOS_TRAINING7_'+str(i)+'.png' ratio = getShadowRatio(filePath)
print("FOR IMAGE: ", filePath, " | Ratio: ", ratio)

In [403…
# TRAIN - Jaccard loss and dice for all saved models over 100 epochs (every 10 epoch)

loss_train = [0.8979, 0.874, 0.8705, 0.8702, 0.865, 0.8625, 0.8579, 0.8614, 0.8546, 0.8566] dice_train = [0.6094, 0.6736, 0.6927, 0.7425, 0.7554, 0.7599, 0.7592, 0.7525, 0.7547, 0.7576] x_val = [10,20,30,40,50,60,70,80,90,100]

fig = plt.figure()
fig.suptitle('Training results over 100 epochs')
plt.xlabel('Epochs')
plt.xticks(x_val,x_val)

plt.plot(x_val, loss_train, label = "Jaccard Loss", marker='o') plt.plot(x_val, dice_train, label = "Dice Score", marker='o') plt.legend()
plt.show()

In [404…
# TEST - Jaccard loss and dice for all saved models over 100 epochs (every 10 epoch)

loss_test = [0.8926, 0.8714, 0.8651, 0.8598, 0.8583, 0.8547, 0.8536, 0.8512, 0.8507, 0.8504] dice_test = [0.6424, 0.6897, 0.7206, 0.7714, 0.7718, 0.787, 0.7866, 0.7705, 0.7739, 0.7688]

fig = plt.figure()
fig.suptitle('Testing results over 100 epochs')
plt.xlabel('Epochs')
plt.xticks(x_val,x_val)

plt.plot(x_val, loss_test, label = "Jaccard Loss", marker='o') plt.plot(x_val, dice_test, label = "Dice Score", marker='o') plt.legend()
plt.show()

In [405…
# OOS TEST - Jaccard loss and dice for all s
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

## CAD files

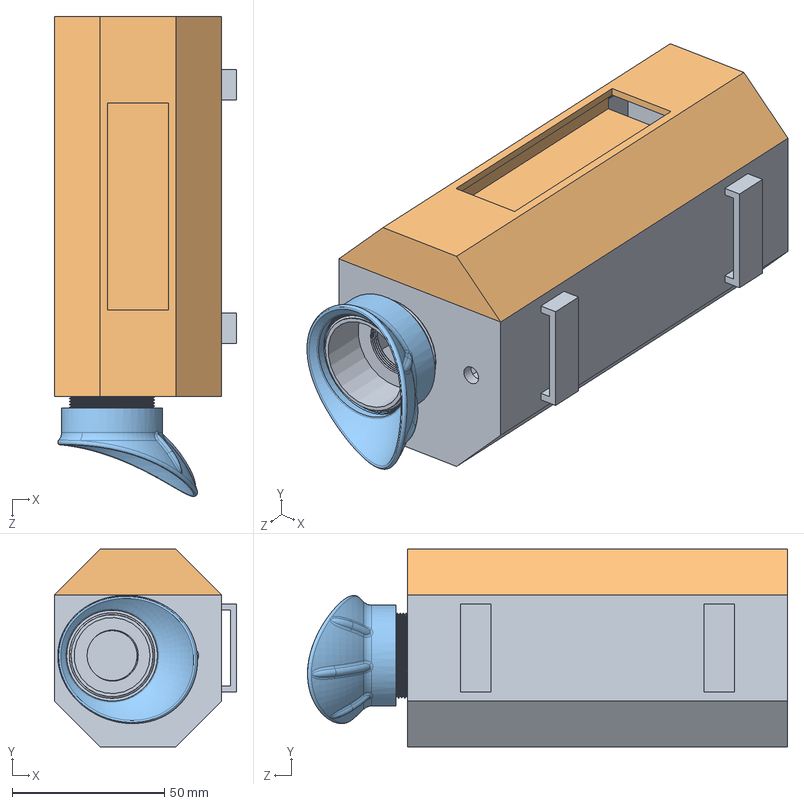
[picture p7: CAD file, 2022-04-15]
CAD_files/box_assembly.SLDASM
60.0 x 65.0 x 157.9 mm
box_bottom_v2
box_top_v2
eyecup_BigMacro

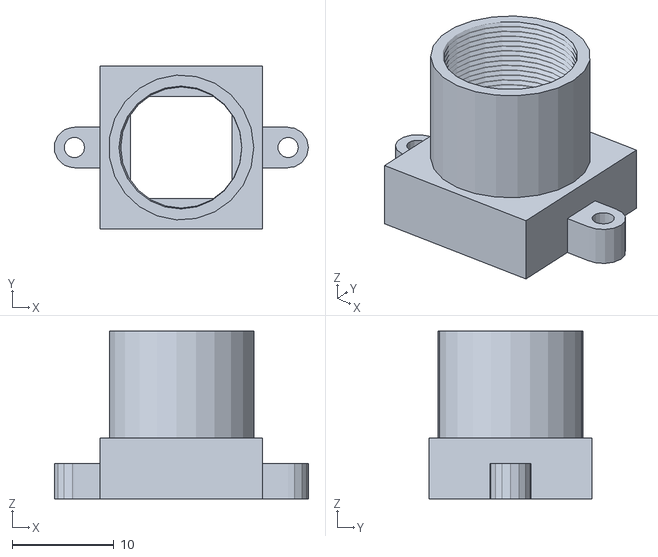
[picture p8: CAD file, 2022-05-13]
CAD_files/M12_lens_mount.stl
25.0 x 16.0 x 16.5

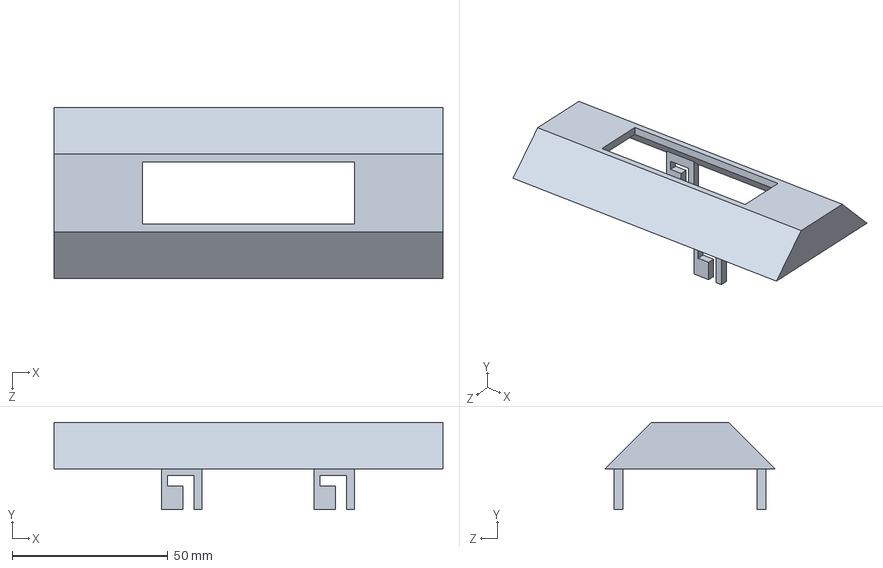
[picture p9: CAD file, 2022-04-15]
CAD_files/box_top.SLDPRT
125.0 x 28.0 x 55.0 mm

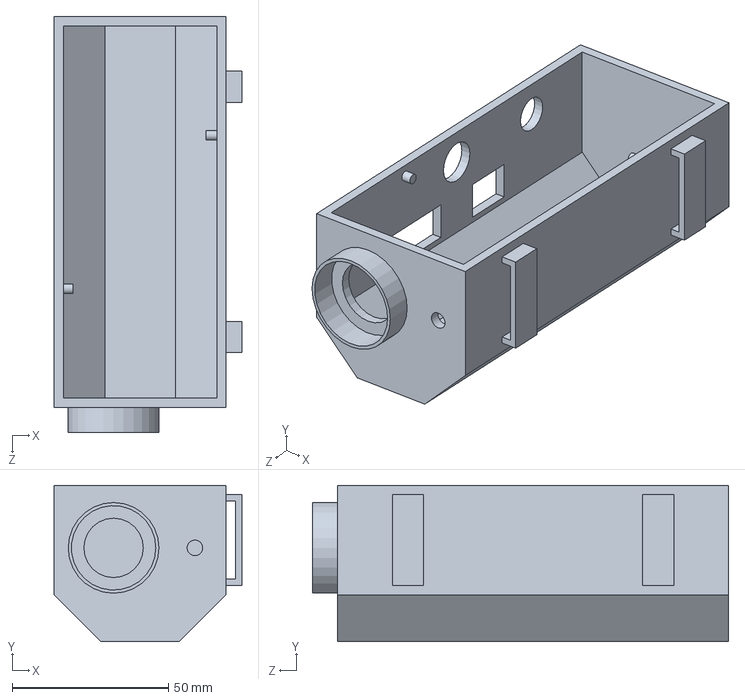
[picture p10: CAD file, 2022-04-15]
CAD_files/box_bottom.SLDPRT
60.0 x 50.0 x 133.0 mm

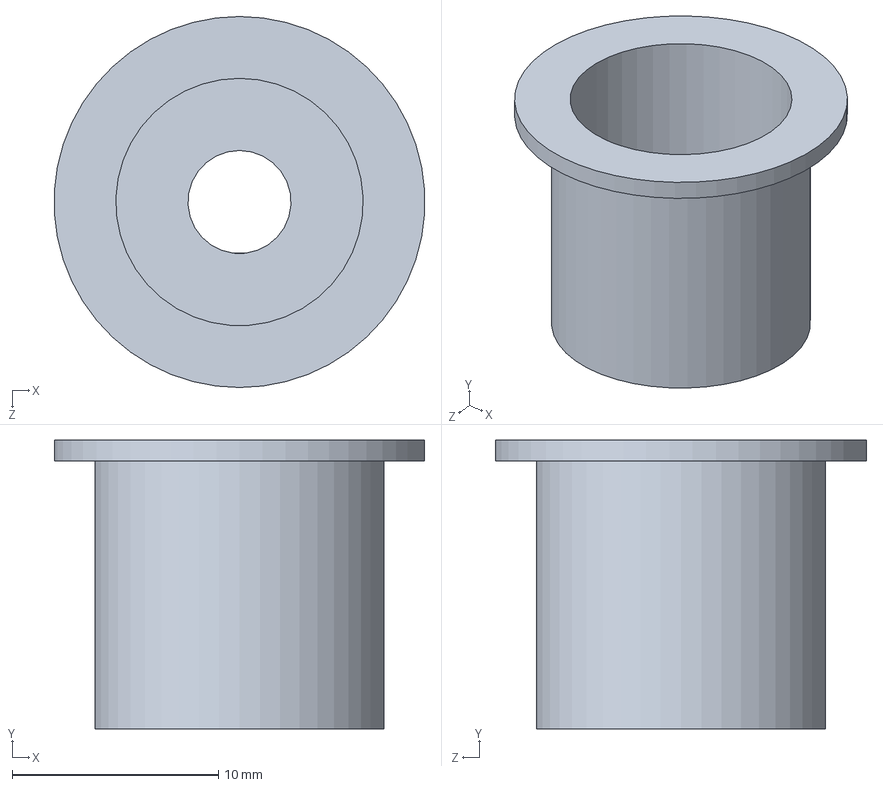
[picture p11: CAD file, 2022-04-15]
CAD_files/LED_holder.SLDPRT
18.0 x 14.0 x 18.0 mm

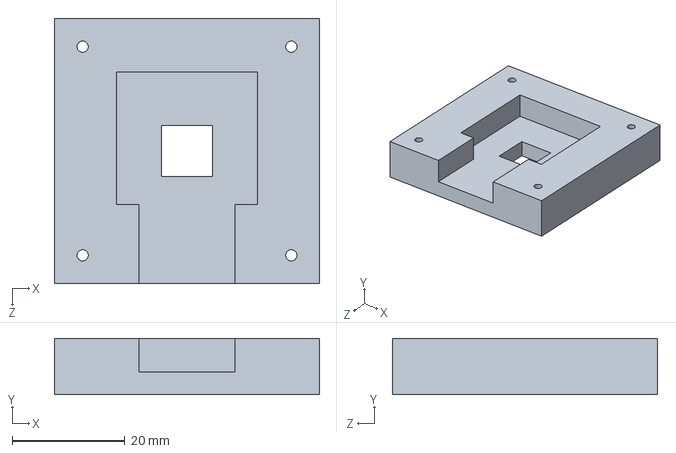
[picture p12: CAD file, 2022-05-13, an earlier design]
CAD_files/picamera_holder_unused.SLDPRT
47.0 x 10.0 x 47.0 mm

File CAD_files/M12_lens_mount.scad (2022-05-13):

include <lib/polyScrewThread_r1.scad>
include <MCAD/units.scad>

base_size = 16;			    // Width and length of square base
base_height = 6;		    // Height of square base
base_cavity_margin = 3;		// Wall thickness of cavity in square base

thread_diameter = 12.25;	// Diameter of thread (M12) + extra for shrinking
thread_margin = 2;		// Thickness of ring around thread
thread_pitch = 0.5;		// Pitch of thread
mount_height = 17.5;	// Overall height of thread

hole_distance = 21;		// Distance between the two mounting holes
hole_diameter = 2.0;	// Diameter of mounting holes
hole_style = 1;			// 0 = flange, 1 = straight bars
hole_height = 3.5;

miniconnector_x = 9.5;
miniconnector_z = 1.85;

enable_thread = true;	// Turn on/off thread (takes a while to render)
enable_base = true;		// Turn on/off square base
enable_mount = true;	// Turn on/off circular mount

// Base
if(enable_base) {
	difference() {
		if(hole_style == 0) {
			hull() {
				// Square base
				translate([0,0,base_height/2])
					cube([base_size, base_size, base_height], center = true);
			
				// Right flange
				translate([hole_distance/2, 0, 0])
					cylinder(r = 2, h = base_height, $fn = 15);
			
				// Left flange
				translate(-[hole_distance/2, 0, 0])
					cylinder(r = 2, h = base_height, $fn = 15);
			}
		} else if(hole_style == 1) {
			union() {
				// Square base
				translate([0,0,base_height/2])
					cube([base_size, base_size, base_height], center = true);
			
				// Right flange
				translate([hole_distance/2, 0, 0])
					cylinder(r = 2, h = hole_height, $fn = 15);
			
				// Left flange
				translate(-[hole_distance/2, 0, 0])
					cylinder(r = 2, h = hole_height, $fn = 15);
	
				// Joining bar
				if(hole_style == 1)
					translate([0,0,hole_height/2])
						cube([hole_distance, 4, hole_height], center = true);
			}
		}

		// Hollow center
		translate([0,0,base_height/2])
			cube([base_size - base_cavity_margin*2, base_size - base_cavity_margin*2, base_height], center = true);
	
		// Right hole
		translate([hole_distance/2, 0, 0])
			cylinder(r = hole_diameter/2, h = hole_height + 2, $fn = 15);
	
		// Left hole
		translate([-hole_distance/2, 0, 0])
			cylinder(r = hole_diameter/2, h = hole_height + 2, $fn = 15);

		// Nappe hole 
		translate([-.75, base_size / 2, miniconnector_z / 2])
			cube([miniconnector_x, base_size / 2, miniconnector_z], center = true);
	}
}

// M12 threaded mount
if(enable_mount) {
	translate([0, 0, base_height - 1])
	difference() {
		cylinder(r = thread_diameter/2 + thread_margin/2, h = mount_height - base_height);
		
		// M12 thread 
		// (Outer diameter, pitch, thread angle, length, resolution, countersink style)
		if(enable_thread)
			screw_thread(thread_diameter, thread_pitch, 55, mount_height + 3, 3.14/2, 0);
		else
			cylinder(r = thread_diameter/2, h = mount_height - base_height);
	}
}

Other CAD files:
CAD_files/LED_holder.STL
CAD_files/box_bottom.STL
CAD_files/box_top.STL
CAD_files/picamera_holder_unused.STL

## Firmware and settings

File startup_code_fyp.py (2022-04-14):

# INSTRUCTIONS:

# CLICK THE GREEN PLAY BUTTON TO START (AT TOP OF THIS WINDOW)
# PRESS THE GREEN DEVICE BUTTON AS MANY TIMES TO TAKE PICTURES
# CLICK THE RED STOP BUTTON TO STOP
# DEVICE WILL BE SAFE TO SHUT DOWN AFTER THE PROGRAMME STOPS

# ----------------------------------------------------------

# For normal functions
import RPi.GPIO as GPIO
from gpiozero import TonalBuzzer, LED, Button
from gpiozero.tones import Tone
#from RPLCD import i2c
from picamera import PiCamera
from signal import pause
from datetime import datetime
from time import sleep
#from subprocess import check_output

# Assign GPIO pins
buzzer = TonalBuzzer(22) # Start up buzzer
torch = LED(21) # Light source LED
led = LED(4) # Start up LED
cam_button = Button(27) # Button to launch camera
#exit_button = Button(17) # Button to exit program
camera = PiCamera()

# # Assign LCD constants
# lcdmode = 'i2c'
# cols = 16
# rows = 2
# charmap = 'A00'
# i2c_expander = 'PCF8574'
# 
# address = 0x27
# port = 1
# 
# lcd = i2c.CharLCD(i2c_expander, address, port=port, charmap=charmap, cols=cols, rows=rows)
# 
# # Start up light
# lcd.close(clear=True)
# lcd.write_string('Starting...')

buzzer.play(Tone("C4")) #Play starting arpeggio
sleep(0.5)
buzzer.play(Tone("E4")) #Play starting arpeggio
sleep(0.5)
buzzer.play(Tone("G4")) #Play starting arpeggio
sleep(0.5)
buzzer.play(Tone("C5")) #Play starting arpeggio
sleep(0.5)
buzzer.stop()

# lcd.close(clear=True)

# Camera action
camera.resolution = (2592, 1944) # Max resolution (3280, 2464) / (2592, 1944) / (640, 480)
camera.framerate = 15 # Frame rate has to be activated for max res to work
camera.brightness = 55

# Button functions
def capture():
    timestamp = datetime.now().isoformat()
    camera.capture('/home/pi/Desktop/Capture Images/%s.png' % timestamp) # Captures image with time stamp

# def stop_code():
#     lcd.close(clear=True)
#     lcd.write_string('Stopping...')
#     lcd.close(clear=True)
#     buzzer.play(Tone("E4"))
#     sleep(1)
#     buzzer.stop()
#     exit()

while True:
    
    #exit_button.when_pressed = stop_code
    
#     lcd_line_1 = "Press green button to start"
#     lcd.write_string(lcd_line_1)
    
    cam_button.wait_for_press() # Code will stop until button is pressed
#    lcd.close(clear=True)

    # When cam_button is pressed
#    lcd.write_string("Capturing photos...")
    torch.on()
    camera.start_preview()
    
    buzzer.play(Tone("C4"))
            
    for i in range(1): # Captures 1 image only
        
        # Adjust time here
        sleep(10)
        
        buzzer.play(Tone("E4"))
        sleep(0.5)
        buzzer.play(Tone("G4"))
        sleep(0.5)
        capture()
            
    camera.stop_preview()
#    lcd.close(clear=True)

    buzzer.stop() # Stop playing
    torch.off()
#    lcd.write_string("Done")
#    lcd.close(clear=True)

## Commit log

2022-04-15 upload cad files
    [LED_holder_v2.SLDPRT, LED_holder_v2.STL, box_assembly_v1.SLDASM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]
2022-05-13 revise CAD files
    [LED_holder.SLDPRT, LED_holder.STL, M12_lens_mount.scad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]
